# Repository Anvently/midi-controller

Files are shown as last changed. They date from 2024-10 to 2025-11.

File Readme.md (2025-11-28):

# DIY midi controller (work in progress)

This repo serves as base documentation and ressources for a project I'm currently working on.
This idea is to create from scratch a MIDI controller to be interfaced with software such as Resolume or Ableton to control in live some lights installation.
The controller integrates : 
- 8x6 rgb button matrix which is based on Novation Launchpad layout.
- for each of the 8 channels : 1 rotary encoder, 4 potentiometer and 1 crossfader 

## RGB button matrix
midi-demo-2cEgF7Ei

led-matrix-schematic

led-matrix-pcb-layout

schematic-matrix-controller

board-controller-layout

## Model case

box-CdF3BtiY

case-drawing

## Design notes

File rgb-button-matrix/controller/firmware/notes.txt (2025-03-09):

Total period is the time required for a full cycle, meaning selecting every row one by one
Row period is the time a row must be turned on. It represent a full BAM cycle
The length of each interrupt must be measured (tI)
With 72MhZ CPU clock, we have 72 cycles/us.

Target frequency => 120Hz
Total period => 1 / 120 => 8.33ms
Row period => 8.33ms / 8 => 1040us

tI => 10us (need to be measured)
T = 1040 - tI = 1040 - 10 = 1030us

With 1040us as BAM length and 8 bits resolution

const uint32_t bamPeriods[8] = {
    4,    // Bit 0 : 2^0 * base_unit
    8,    // Bit 1 : 2^1 * base_unit
    16,   // Bit 2 : 2^2 * base_unit
    32,   // Bit 3 : 2^3 * base_unit
    64,   // Bit 4 : 2^4 * base_unit
    128,  // Bit 5 : 2^5 * base_unit
    256,  // Bit 6 : 2^6 * base_unit
    532   // Bit 7 : restant pour atteindre ~1040µs total
};

With 6 bits resolution and 1024us as BAM length (122Hz)

const uint32_t bamPeriods[6] = {
    16,   // Bit 2 : 2^2 * base_unit
    32,   // Bit 3 : 2^3 * base_unit
    64,   // Bit 4 : 2^4 * base_unit
    128,  // Bit 5 : 2^5 * base_unit
    256,  // Bit 6 : 2^6 * base_unit
    512
};

Button scanning with 6 bits and 122Hz :
Each button is scanned at a 9.22ms interval.

Intensity :
green, 100ohm : 7.45mA / 8mA (2.95V / 2.95V)
blue, 100ohm : 6.63mA / 6.64mA (single column : 7.5mA) (3V / 3.1V)
red, 150ohm : 8.87mA / 8.81mA (single column : 9.7mA) (2.37V / 2.37V) 

With 3.3V as output of UDN2981A :  
Red => 54ohm, 50ohm and 3.45V source => 30mA
Green => 
4.86V

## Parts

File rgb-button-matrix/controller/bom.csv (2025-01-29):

Reference | Value | LSCS part number | Description | Qty
C1,C3,C4,C5,C6,C7,C12,C13,C14,C15,C17,C19,C21,C22 | 100n | C1525 | 16V 100nF X7R ±10% | 14
C2 | 4u7 | C19666 | 16V 4.7uF X5R ±10% | 1
C8 | 10u | C15850 | 25V 10uF X5R ±10% | 1
C9,C10 | 30p | C1570 | 50V 30pF C0G ±5% | 2
C11,C16,C18,C20 | 1u |  | 16V 1u X5R ±10% | 4
D1,D3 | Red led | C2286 | Light emitting diode | 2
D2 | MBR1020VL |  | 20V, 1A, 340 mV, Schottky Diode Rectifier, SOD-123F | 1
F1 | 1A |  | Fuse | 1
J1,J2,J4 | Conn_01x03_Pin |  | Generic connector, single row, 01x03, script generated | 3
J3,J6 | Conn_01x02_Pin |  | Generic connector, single row, 01x02, script generated | 2
J5 | USB_C_Receptacle_USB2.0_14P |  | USB 2.0-only 14P Type-C Receptacle connector | 1
J7 | Conn_01x04_Pin |  | Generic connector, single row, 01x04, script generated | 1
J10,J11,J12,J13,J14 | Conn_02x04_Odd_Even |  | Generic connector, double row, 02x04, odd/even pin numbering scheme (row 1 odd numbers, row 2 even numbers), script generated (kicad-library-utils/schlib/autogen/connector/) | 5
R1,R10 | 1k | C21190 | 1kΩ 100mW Thick Film Resistors | 2
R2,R4 | 2.2k | C25879 | 2.2kΩ 62.5mW Thick Film Resistors | 2
R3,R11,R12,R13 | 10k | C25744 | 10kΩ 62.5mW Thick Film Resistors | 4
R5,R6 | 22 |  | Resistor | 2
R7 | 4.7k |  | Resistor | 1
R8,R9 | 5.1k |  | Resistor | 2
R14,R16,R17,R18,R19,R20 | 50 |  | Resistor | 6
R15,R21,R22,R23,R24,R25,R26,R27,R28,R29,R30,R31 | 20 |  | Resistor | 12
R32,R33,R34,R35,R36,R37 | 100k | C25803 | 100kΩ 100mW Thick Film Resistors | 6
SW1 | SW_Push | C318884 | Tactile Switch | 1
U1 | STM32F103C8Tx | C23922 | STMicroelectronics Arm Cortex-M3 MCU, 64KB flash, 20KB RAM, 72 MHz, 2.0-3.6V, 37 GPIO, LQFP48 | 1
U2 | LD1117S33TR_SOT223 |  | 800mA Fixed Low Drop Positive Voltage Regulator, Fixed Output 3.3V, SOT-223 | 1
U3 | TPIC6595 |  | TPIC6B595 - Power Logic 8-bit Shift Register, DIP-8/SOIC-8 | 1
U4,U5,U6 | 74HC595 |  | 74HC595 8-bit serial in/out Shift Register 3-State Outputs | 3
U7,U8,U9 | UDN2981A |  | 8-Channel Source Transistor Array 500mA, 50V, DIP-18-18W | 3
U10 | 74HC165 |  | 74HC165 - Shift Register, 8-bit, Parallel Load | 1
Y1 | 8Mhz | C115962 | Two pin crystal, small symbol | 1

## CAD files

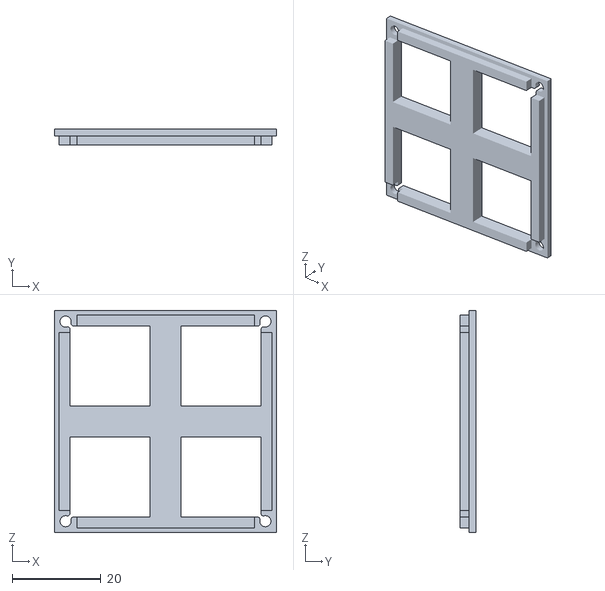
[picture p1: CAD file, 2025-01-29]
rgb-button-matrix/matrix/button-spacer.stl
50.0 x 3.50 x 50.0

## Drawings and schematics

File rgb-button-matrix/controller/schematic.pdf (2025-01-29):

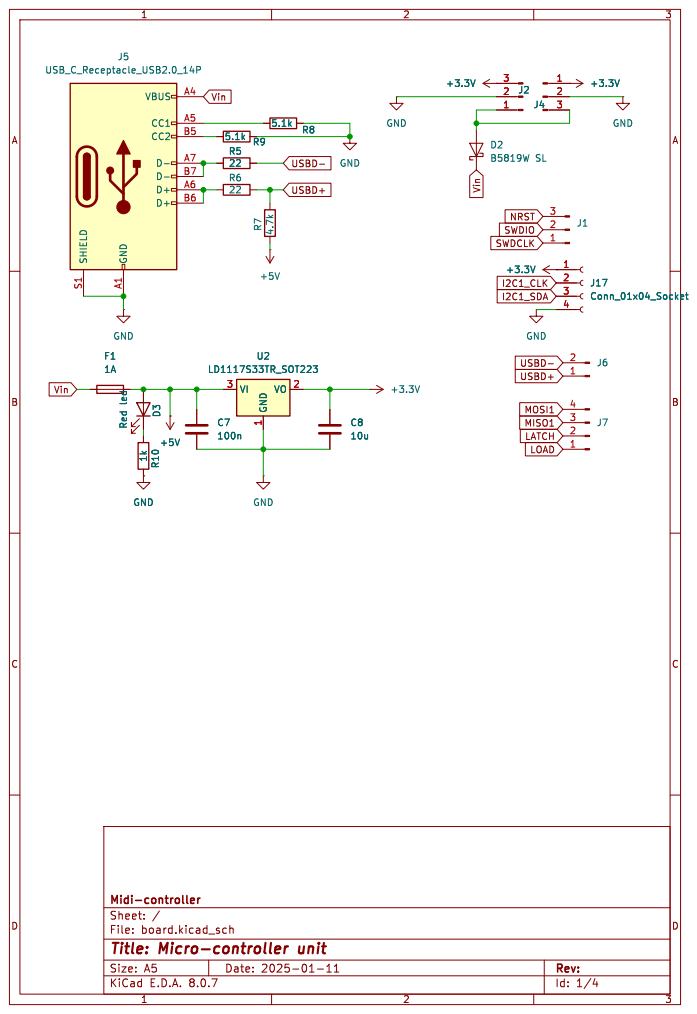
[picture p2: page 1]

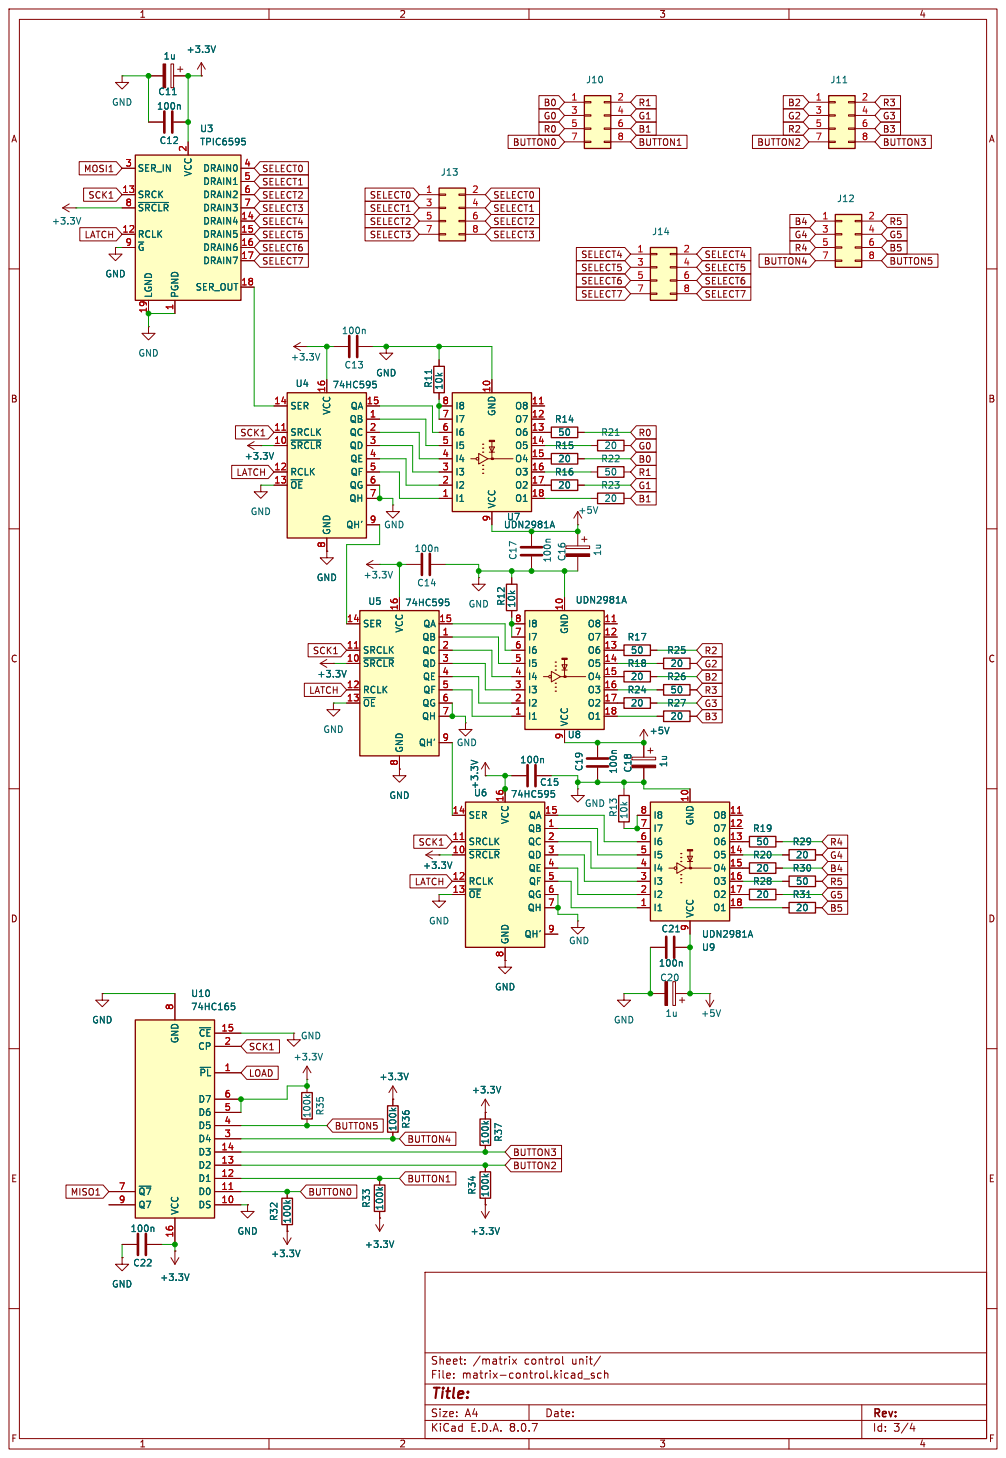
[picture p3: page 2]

1 RCLK 12 SRCK 13 DRAIN4 14 DRAIN5 15 DRAIN6 16 DRAIN7 17 SER_OUT 18 LGND 19 VCC

8 QH' 9 U4 74HC595 GND GND GND

9 +3.3V U4 74HC595 QB 1 ~{SRCLR} 10 SRCLK 11 RCLK 12 ~{OE} 13 SER 14 QA 15 VCC 16 QC 2 QD 3 QE 4 QF 5 QG 6 QH 7 GND

8 QH' 9U5 74HC595 QB 1 ~{SRCLR} 10 SRCLK 11 RCLK 12 ~{OE} 13 SER 14 QA 15 VCC 16 QC 2 QD 3 QE 4 QF 5 QG 6 QH 7 GND

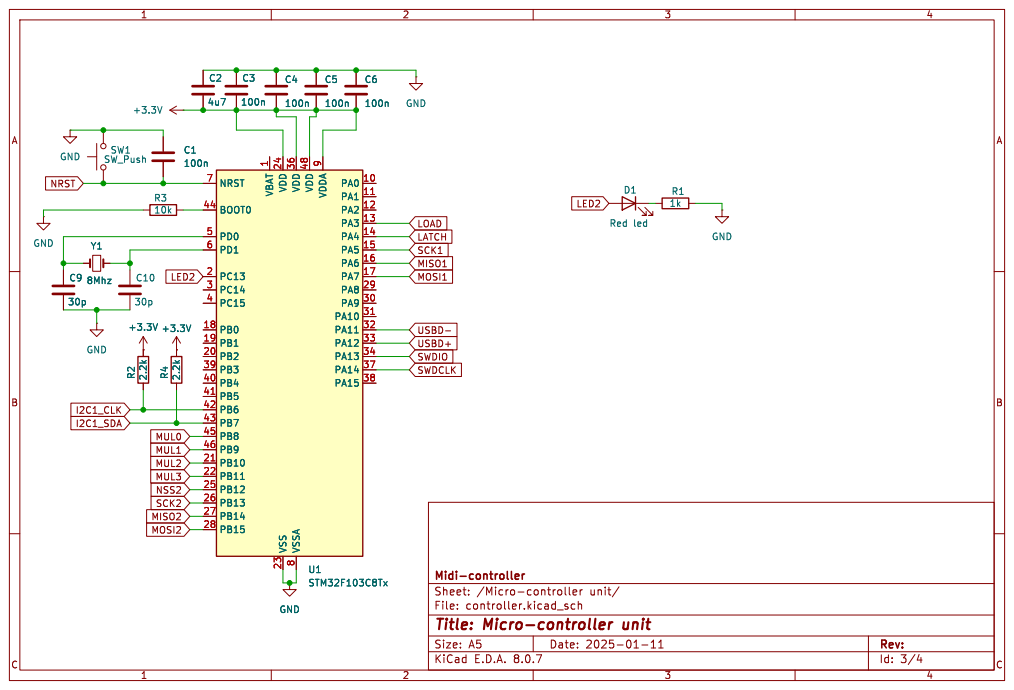
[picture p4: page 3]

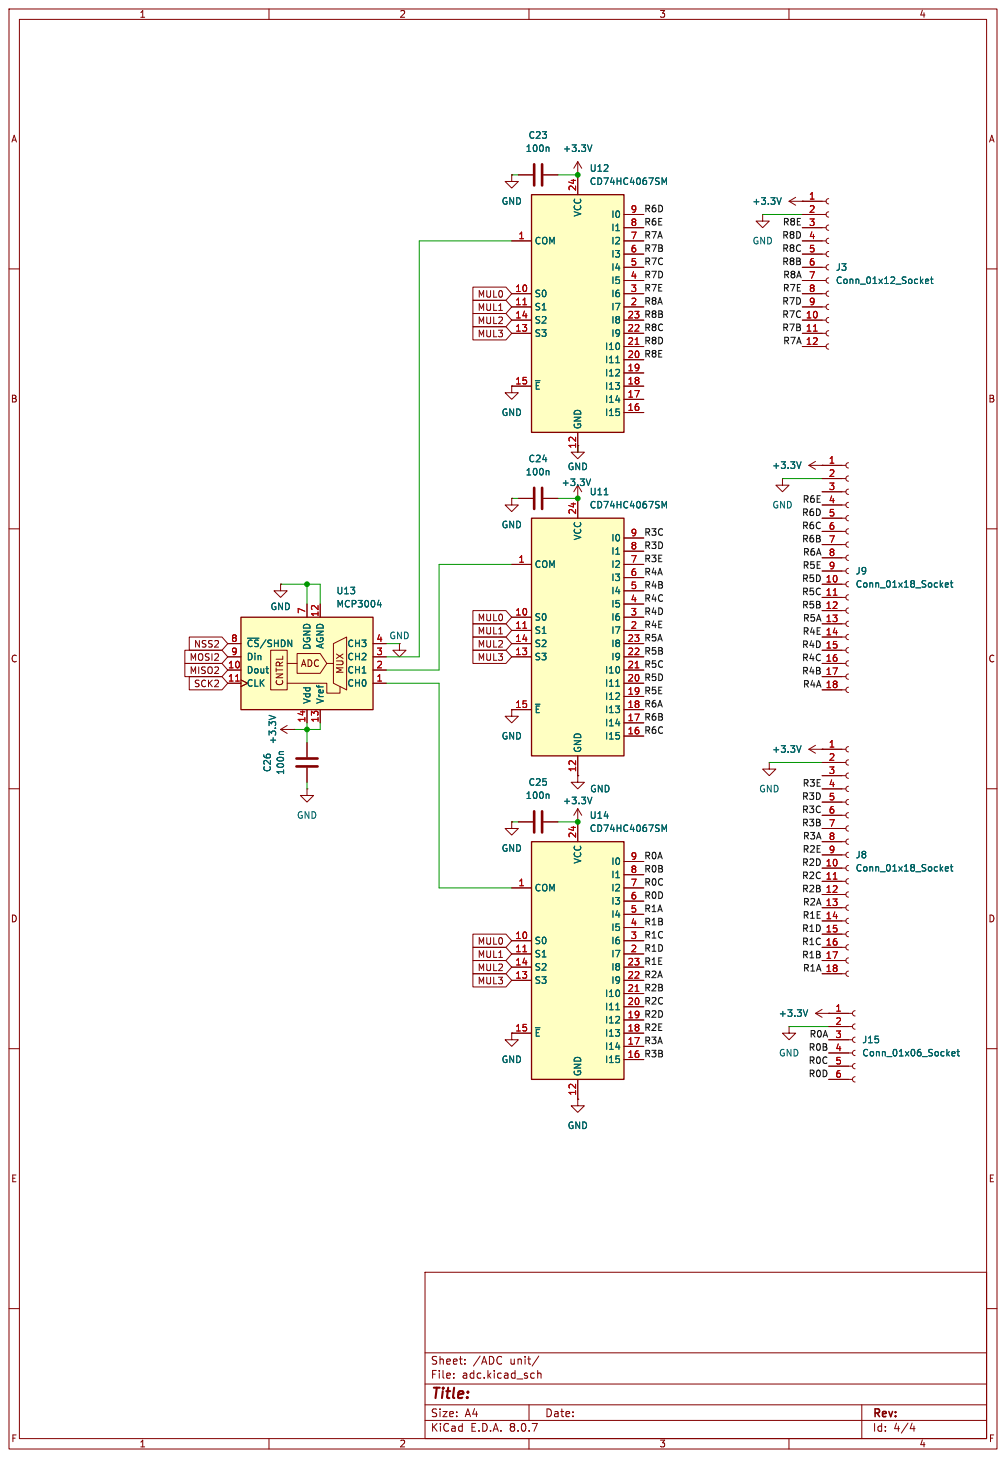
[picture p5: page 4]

Id: 4/4 Title: File: adc.kicad_sch Sheet: /ADC unit/

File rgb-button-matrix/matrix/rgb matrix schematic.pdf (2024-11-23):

## ROW1 Control

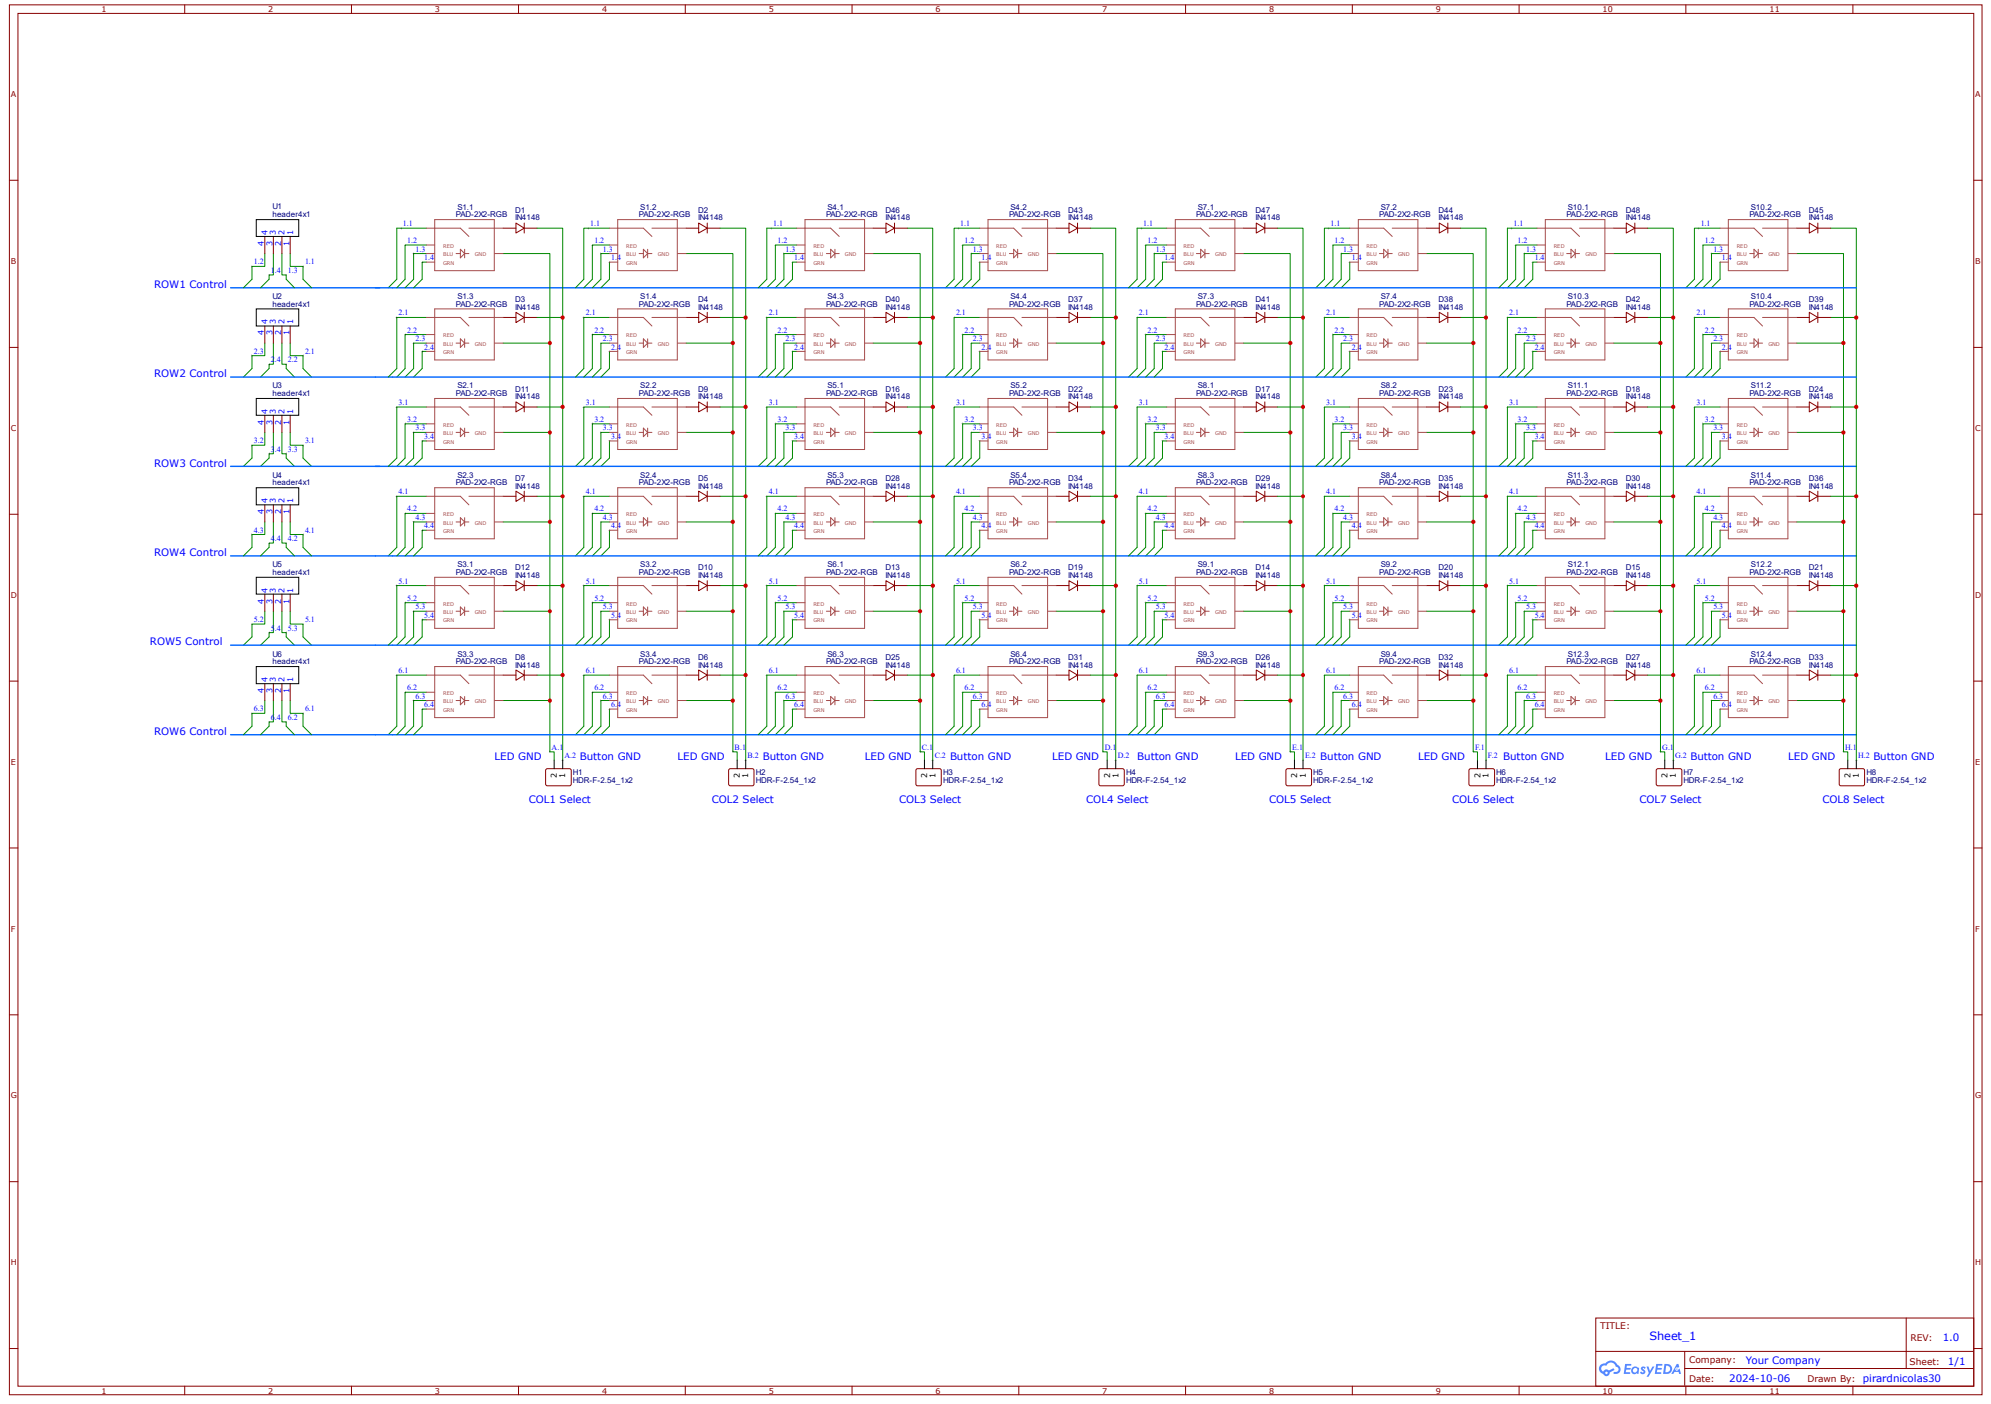
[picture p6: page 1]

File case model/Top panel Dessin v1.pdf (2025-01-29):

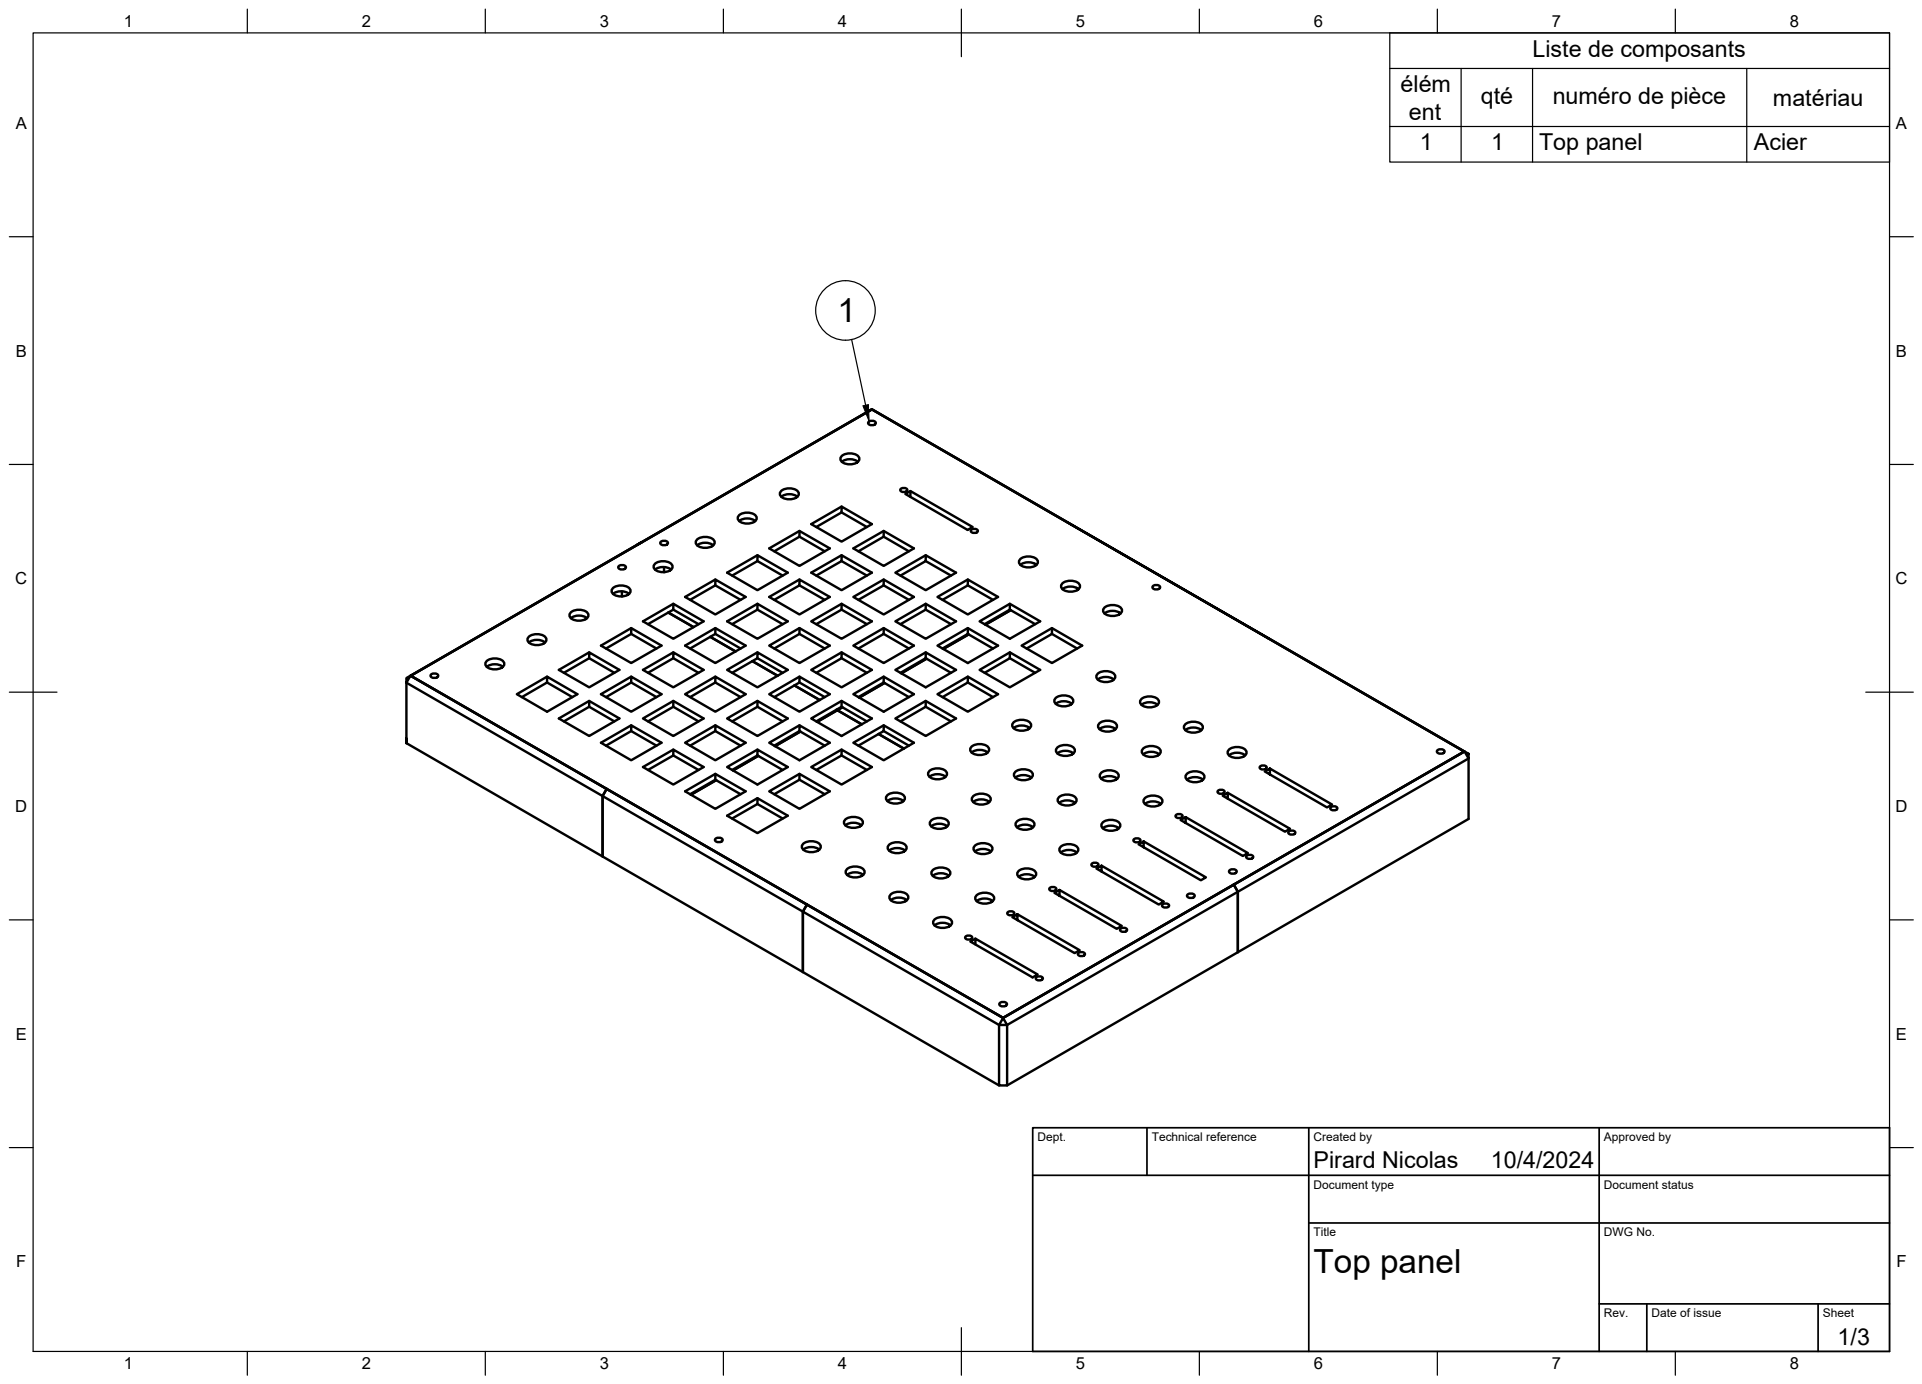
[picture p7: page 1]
Title; DWG No.; Rev.; Date of issue; Sheet; Top panel

Liste de composants

élém ent | qté | numéro de pièce | matériau

1 | 1 | Top panel | Acier

Dept. | Technical reference | Created by Pirard Nicolas 10/4/2024 | Approved by

Document type | Document status

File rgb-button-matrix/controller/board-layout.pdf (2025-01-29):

J5
D2 | U11 R⁹

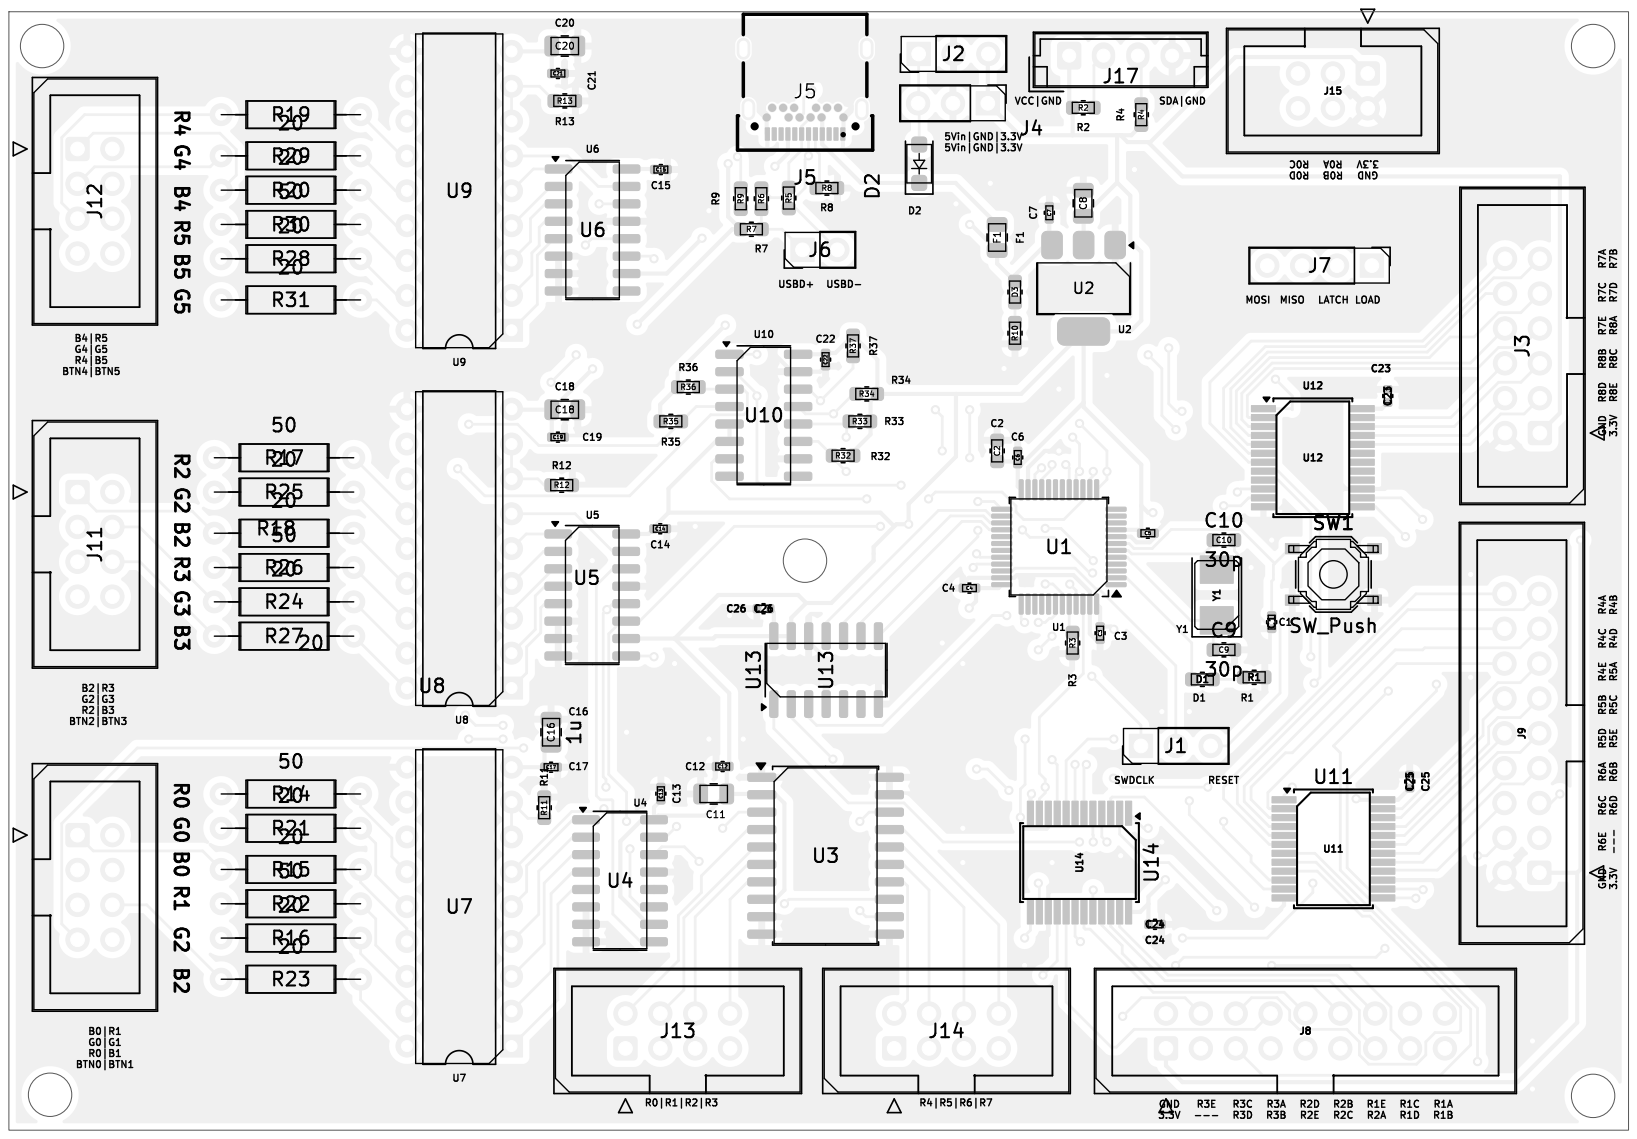
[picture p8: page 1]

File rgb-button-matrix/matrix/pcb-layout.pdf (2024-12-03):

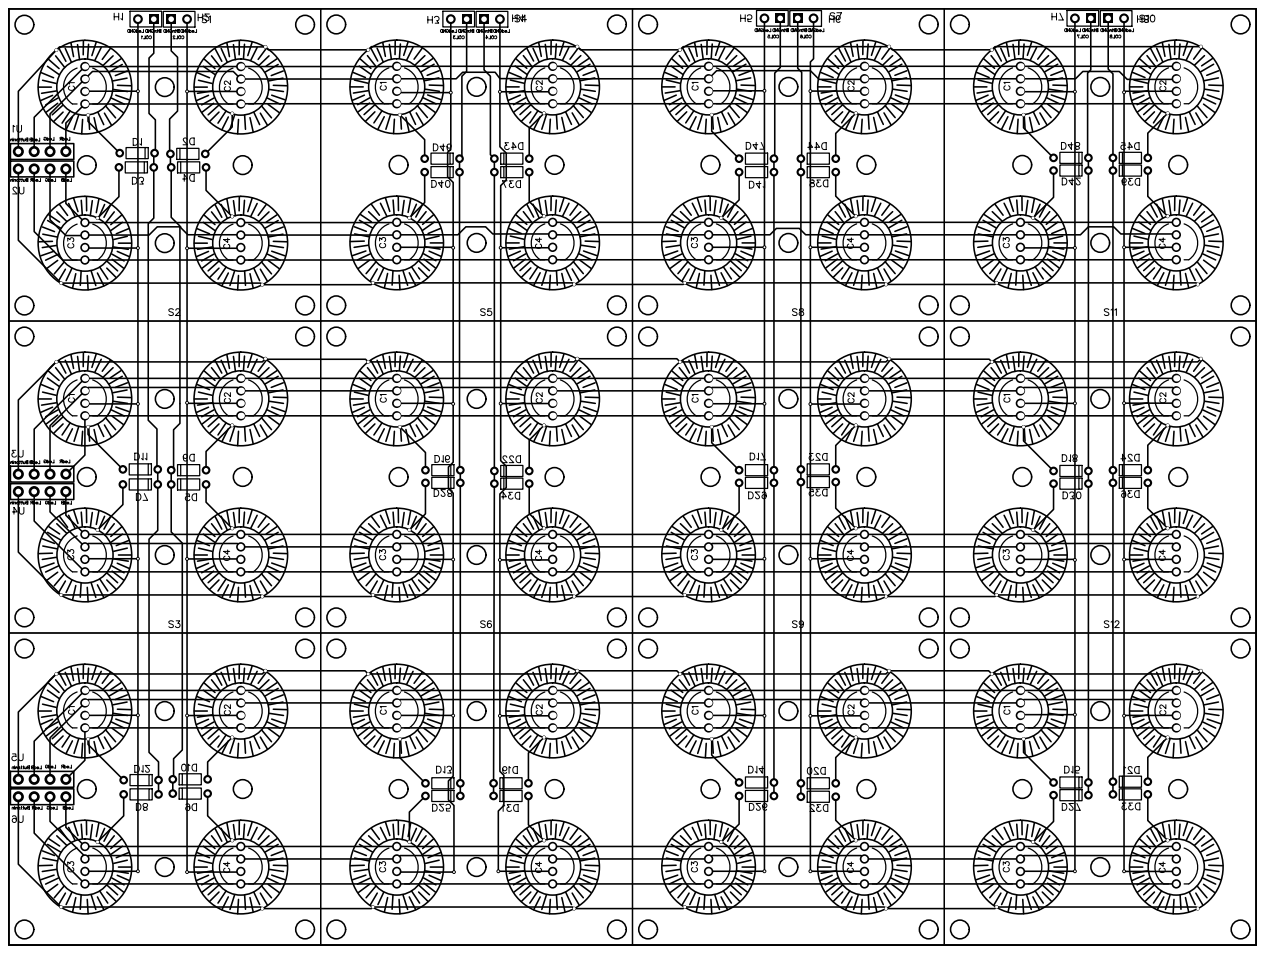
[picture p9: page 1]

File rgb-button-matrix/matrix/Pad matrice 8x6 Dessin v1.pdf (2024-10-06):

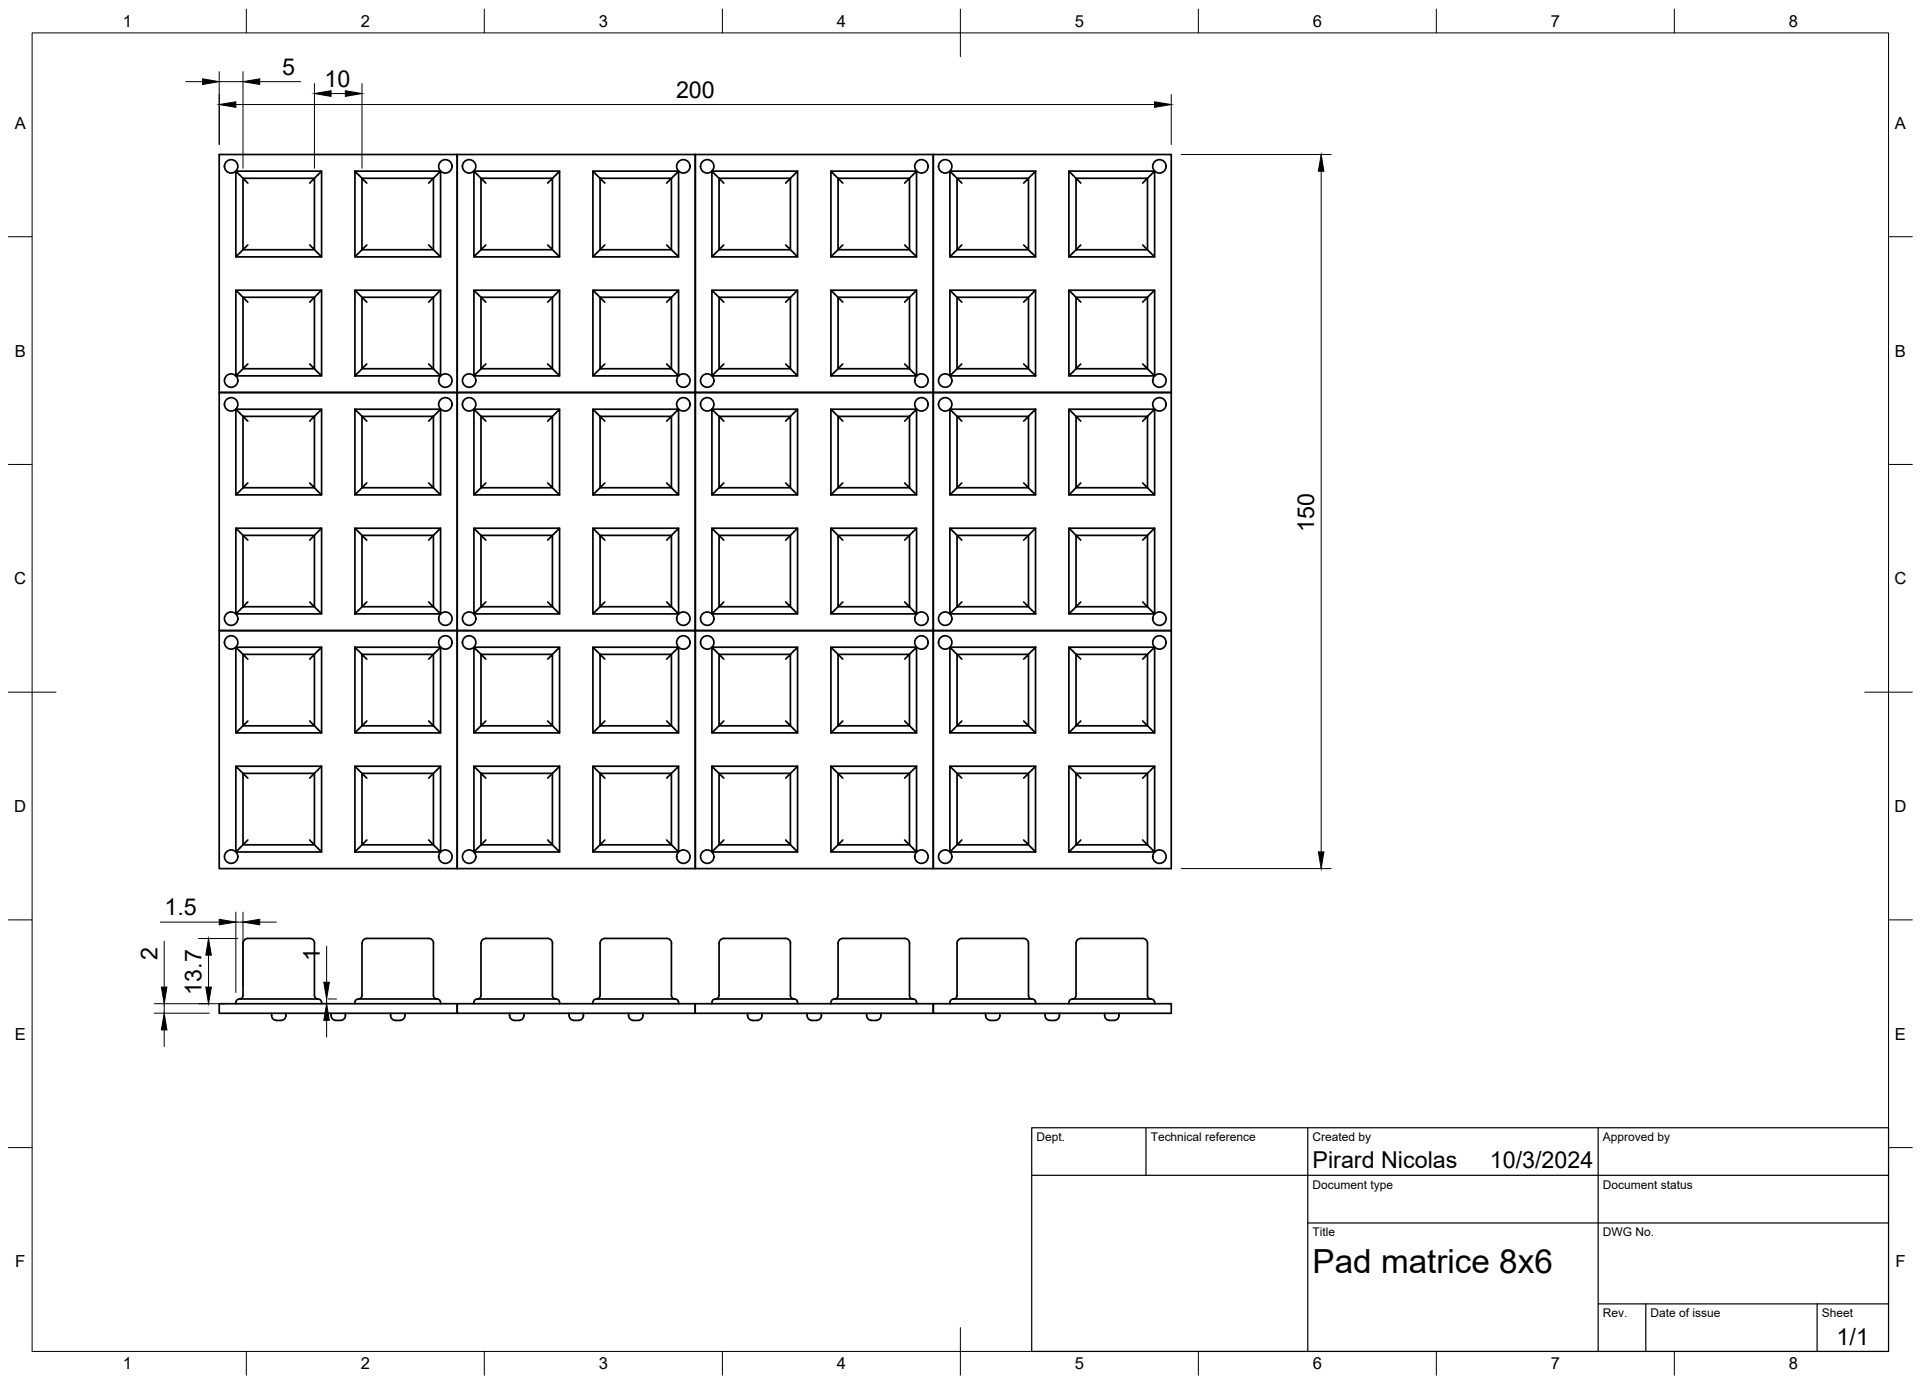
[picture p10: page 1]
Title; DWG No.; Rev.; Date of issue; Sheet; Pad matrice 8x6

Dept. | Technical reference | Created by Pirard Nicolas 10/3/2024 | Approved by

Document type | Document status

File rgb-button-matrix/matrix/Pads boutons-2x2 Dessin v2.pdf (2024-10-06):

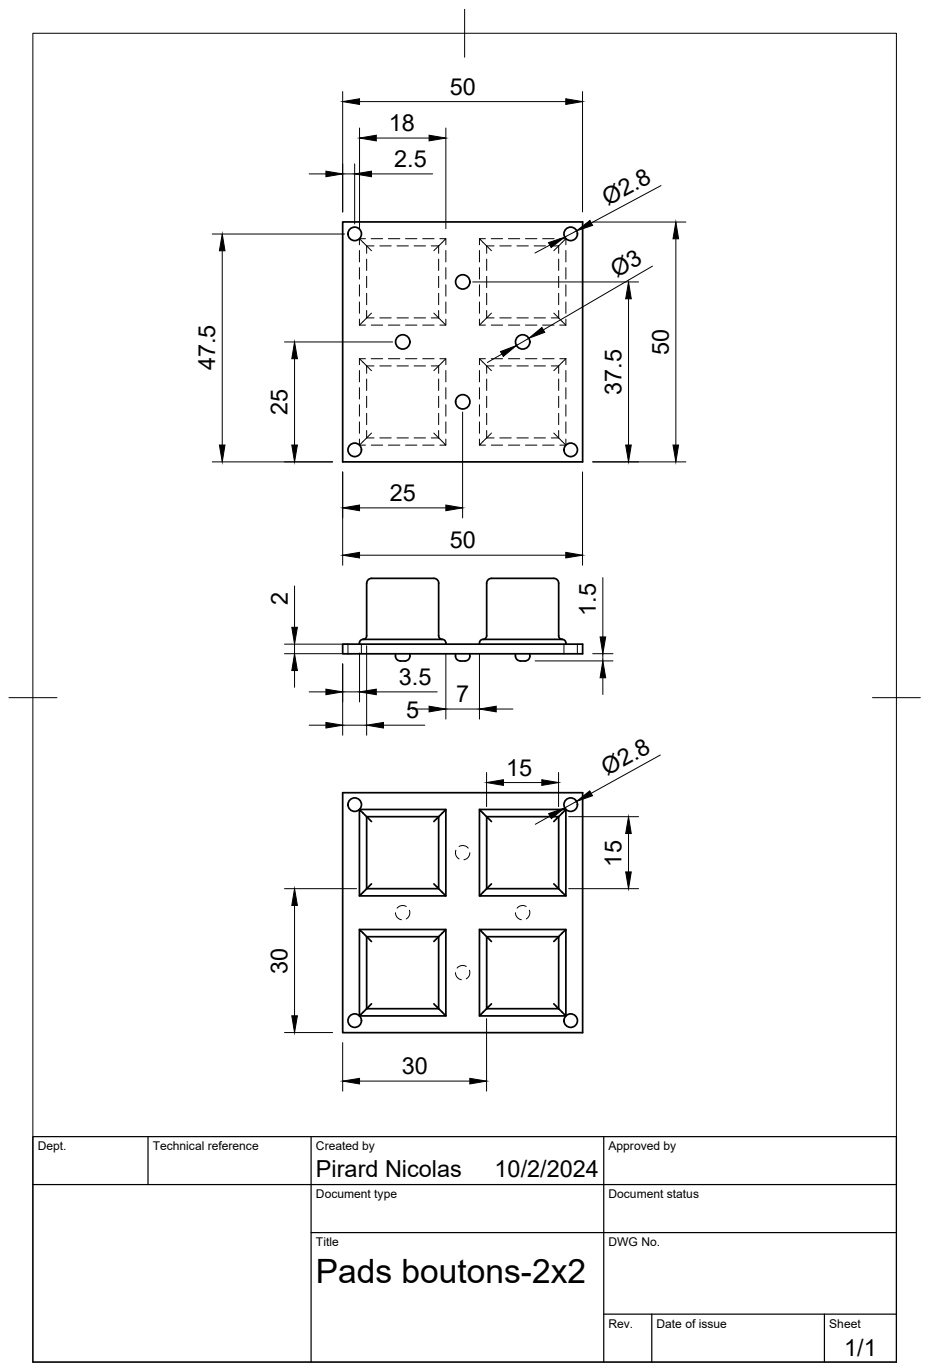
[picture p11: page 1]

Dept. | Technical reference | Created by Pirard Nicolas 10/2/2024 | Approved by

Document type | Document status

Title Pads boutons-2x2 | DWG No.

Rev. | Date of issue | Sheet 1/1

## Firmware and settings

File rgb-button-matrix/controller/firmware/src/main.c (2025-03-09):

#include "stm32f0xx_hal.h"
#include <memory.h>
#include <matrix.h>

#define OFFSET_PERIOD 5 // Measured duration of interrupt procedure and spi transmission
#define EXTRA_PERIOD 0 // Measured duration of button matrix routine + potentiometer reading during the last BAM period

volatile t_color			colors[NBR_ROWS][NBR_COLUMNS];
TIM_HandleTypeDef	hTIM14;

const uint32_t		BAM_PERIODS[COLOR_RESOLUTION] = {
	// 4UL * BAM_PRESCALER - OFFSET_PERIOD,    // Bit 0 : 2^0 * base_unit
    // 8UL * BAM_PRESCALER - OFFSET_PERIOD,    // Bit 1 : 2^1 * base_unit
    16UL * BAM_PRESCALER - OFFSET_PERIOD,   // Bit 2 : 2^2 * base_unit
    32UL * BAM_PRESCALER - OFFSET_PERIOD,   // Bit 3 : 2^3 * base_unit
    64UL * BAM_PRESCALER - OFFSET_PERIOD,   // Bit 4 : 2^4 * base_unit
    128UL * BAM_PRESCALER - OFFSET_PERIOD,  // Bit 5 : 2^5 * base_unit
    256UL * BAM_PRESCALER - OFFSET_PERIOD,  // Bit 6 : 2^6 * base_unit
    512UL * BAM_PRESCALER - OFFSET_PERIOD - EXTRA_PERIOD // 
};


// #define SET_COLOR(row, col, value) (rows[row] = ((value) & ~(0b111 << COLUMN_SHIFT(col))) | ((value) << COLUMN_SHIFT(col)))

void LED_Init();
void Timer2_Init(void);
void SystemClock_Config(void);
void SPI1_Init(void);
void SPI2_Init(void);
void SPI_GPIO_Init(void);

void	Error_Handler(void) {
	HAL_GPIO_WritePin(LED_GPIO_PORT, LED_PIN, GPIO_PIN_SET);
}

void TIM14_IRQHandler(void) {
	static uint8_t		current_row = 0;
	static uint8_t		current_bam_bit = 0;
	uint32_t	data;
	uint8_t		button_reading;

	data = color_data[current_row][current_bam_bit];

	//Load 74HC165 input into parallel shift register
	RESET_PIN(GPIOA, LOAD_PIN);
	SET_PIN(GPIOA, LOAD_PIN);

	RESET_PIN(GPIOA, LATCH_PIN);
	SPI1->CR1 |= (SPI_CR1_MSTR | SPI_CR1_SPE); //Enable master mode and SPI
	SPI1->DR = (data >> 16); //Write 16 first MSB
	while ((SPI1->SR & SPI_SR_TXE) == 0); //While tx_buffer is not empty
	while ((SPI1->SR & SPI_SR_RXNE) == 0); // While rx_buffer is not ready
	button_reading = (uint8_t)(SPI1->DR >> 8); //Read received data
	SPI1->DR = (data & 0x0000FFFF); //Send 16 LSB
	while ((SPI1->SR & SPI_SR_TXE) == 0); //While tx_buffer is not empty
	while ((SPI1->SR & SPI_SR_RXNE) == 0); // While rx_buffer is not ready
	(void)SPI1->DR;
	SET_PIN(GPIOA, LATCH_PIN);

	if (current_bam_bit == COLOR_RESOLUTION - 1) { // If next period is the longest one => 512us
		uint8_t	input = (button_state[current_row] ^ button_reading) & 0b00111111;

		for (uint8_t i = 0; input != 0; input >>= 1, i++) {
			if (input & 1) {
					event_push(NEW_EVENT(current_row, //row
						(i % 2 ? i - 1 : i +1), //col (inverted)
						button_reading & (1 << i))); // 1=> press / 0=> release
			}
		}
		button_state[current_row] = button_reading;
		handle_events();
		read_adc();
	}

	if (current_bam_bit == COLOR_RESOLUTION - 2) { //If next period is 2nd longest one => 256us
		update_colors_data(); //Update colors data
		// Init DMA transfer for buttons and pot readings DMA1_Channel2
	}

	// Setup next interrupt by changing autoreload value
	TIM14->ARR = BAM_PERIODS[current_bam_bit];
	TIM14->CNT = 0;

	current_bam_bit = (current_bam_bit + 1) % COLOR_RESOLUTION;
	if (current_bam_bit == 0) // If end of cycle, select the next column
		current_row = (current_row + 1) % NBR_ROWS;
	TIM14->SR &= (uint16_t)~TIM_IT_UPDATE;
}

void SysTick_Handler(void) {
	HAL_IncTick();
}

int main(void) {
	HAL_Init();

	LED_Init();
	SPI_GPIO_Init();
	SPI1_Init();
	SPI2_Init();

	SystemClock_Config();
	Timer2_Init();
	HAL_NVIC_SetPriority(TIM14_IRQn, 0, 0);
    HAL_NVIC_EnableIRQ(TIM14_IRQn);

	// set_col(0, (t_color){255, 0, 0});
	// set_col(1, (t_color){0, 255, 0});
	// set_col(2, (t_color){255, 0, 0});
	// set_col(3, (t_color){255, 0, 0});
	// set_col(4, (t_color){0, 255, 0});
	// set_col(5, (t_color){0, 0, 255});
	
	trigger_color_wheel();
	// show_intensity(1, 1, 1);
	// set_col(0, (t_color){255, 255, 0});
	// set_row(0, (t_color){255, 0, 0});
	// set_row(2, (t_color){247, 0, 0});
	// set_row(3, (t_color){85, 0, 0});
	// set_row(5, (t_color){85, 0, 0});

	while (1);

}

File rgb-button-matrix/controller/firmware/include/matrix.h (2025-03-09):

#include "stm32f0xx_hal.h"
#include "stdbool.h"

#define NBR_COLUMNS 6
#define NBR_ROWS 8
#define COLOR_RESOLUTION 6
#define BAM_PRESCALER 1

#define RED_DAMPENING 1.f
#define GREEN_DAMPENING 0.5f
#define BLUE_DAMPENING 0.5f

#define LATCH_PIN		GPIO_PIN_4
#define LOAD_PIN		GPIO_PIN_3
#define LED_PIN			GPIO_PIN_13
#define LED_GPIO_PORT	GPIOC
#define ADC_NSS_PIN		GPIO_PIN_12
#define ADC_SCK_PIN		GPIO_PIN_13
#define ADC_MISO_PIN	GPIO_PIN_14
#define ADC_MOSI_PIN	GPIO_PIN_15
#define ADC_MUL0_PIN	GPIO_PIN_8
#define ADC_MUL1_PIN	GPIO_PIN_9
#define ADC_MUL2_PIN	GPIO_PIN_10
#define ADC_MUL3_PIN	GPIO_PIN_11

#define SET_PIN(PORT, PINS)((PORT)->BSRR = (PINS))
#define RESET_PIN(PORT, PINS)((PORT)->BSRR = ((PINS) << 16))
#define ADC_MUL_SELECT(val) (GPIOB->ODR = (GPIOB->ODR & ~(0b1111 << 8)) | ((val) << 8))

#define GET_BIT_VALUE(r, g, b) (((r) << 0) | ((g) << 1) | ((b) << 2))
#define COLUMN_SHIFT(col) ((((col) / 2 ) * 8) + (((col) % 2) * 3) + 8)

#define BUTTON_EVENT_SIZE 10

typedef struct s_color {
	uint8_t	r;
	uint8_t	g;
	uint8_t	b;
	uint8_t	padding;
}	t_color;


// Y(Row) - X(Col) - state - Unused
// YYY - XXX - S - U
typedef __uint8_t t_button_event;
typedef struct {
	int				head;
	int				tail;
	int				max;
	t_button_event	data[BUTTON_EVENT_SIZE];
}	t_btn_queue; // FIFO circular buffer

extern volatile t_btn_queue	event_queue;
#define BTN_PRESS_EVENT 1
#define BTN_RELEASE_EVENT 0
#define NEW_EVENT(row, col, type) (((row) << 5) | ((col) << 2) | ((type) << 1))
#define EVENT_ROW(event) (((event) & 0b11100000) >> 5)
#define EVENT_COL(event) (((event) & 0b00011100) >> 2)
#define EVENT_TYPE(event) (((event) & 0b00000010) >> 1)

extern volatile t_color			colors[NBR_ROWS][NBR_COLUMNS];
extern volatile uint8_t			button_state[NBR_ROWS];
extern volatile uint32_t		color_data[NBR_ROWS][COLOR_RESOLUTION];

int				event_push(t_button_event event);
t_button_event	event_pop(void);
void			handle_events(void);
void			read_adc(void);

void	set_col(uint8_t col, t_color color);
void	set_row(uint8_t row, t_color color);
void	trigger_color_wheel(void);
void	show_intensity(uint8_t r, uint8_t g, uint8_t b);
void	check_button_state(uint8_t button_reading, uint8_t current_row);
uint8_t	spi_transmit_receive(uint32_t data);
void	button_press(uint8_t row, uint8_t col);
void	button_release(uint8_t row, uint8_t col);
void	update_colors_data(void);

void	Error_Handler(void);

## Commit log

2024-11-23 added datasheets and rgb matrix schematic pdf
    [multiplex.kicad_pcb, multiplex.kicad_sch]
2024-11-29 reorder arborescence
    [multiplex.kicad_pcb, multiplex.kicad_sch]
2024-11-29 added readme and pcb layouts
2024-12-10 test pwm vs bam
2024-12-10 checking bam against pwm
2024-12-10 bam fix ? added bam prescaler
    [main.c]
2024-12-10 bam color wheel
2024-12-11 bam fixed and working git status Clock was set to 16MHz instead of 72MHz
    [main.c]
2024-12-18 implemented button handling in code
2024-12-18 button implemented
2024-12-19 - lots of optimization on timer interrupt handler - not using any HAL function anymore - spi data are sent using 16bits frame format - no function call inside interrupt - calculation of color data ar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
2024-12-27 Interrupt is now taking about 1-2us vs 20-30us. Measured and substracted 3us offset macro to bam periods
2025-01-08 fixed spi transmit in interrupt, switch to 7 color resolution, measured spi transmission is actually 5us
    [main.c, matrix.h]
2025-01-29 add board assembly pdf
    [bom.csv, button-spacer.stl, multiplex.kicad_pcb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]
2025-03-09 switched to f030r8 environment, added circular buffer for button event, need to measure and adjust bam timings
2025-03-09 started to implement DMA with usart
